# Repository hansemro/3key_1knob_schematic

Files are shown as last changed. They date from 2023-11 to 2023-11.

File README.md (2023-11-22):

3 Key + 1 Knob Minipad Schematic
================================

This repo contains an approximate KiCAD schematic and PCB layout for a 3 Key + 1 Knob minipad with
a CH552 USB MCU. Keys are each lit with an addressable NeoPixel (or similar) RGB LED.

## License

This work is licensed under a
[Creative Commons Attribution 4.0 International License][cc-by].

[][cc-by]

[cc-by]: http://creativecommons.org/licenses/by/4.0/
[cc-by-image]: https://i.creativecommons.org/l/by/4.0/88x31.png

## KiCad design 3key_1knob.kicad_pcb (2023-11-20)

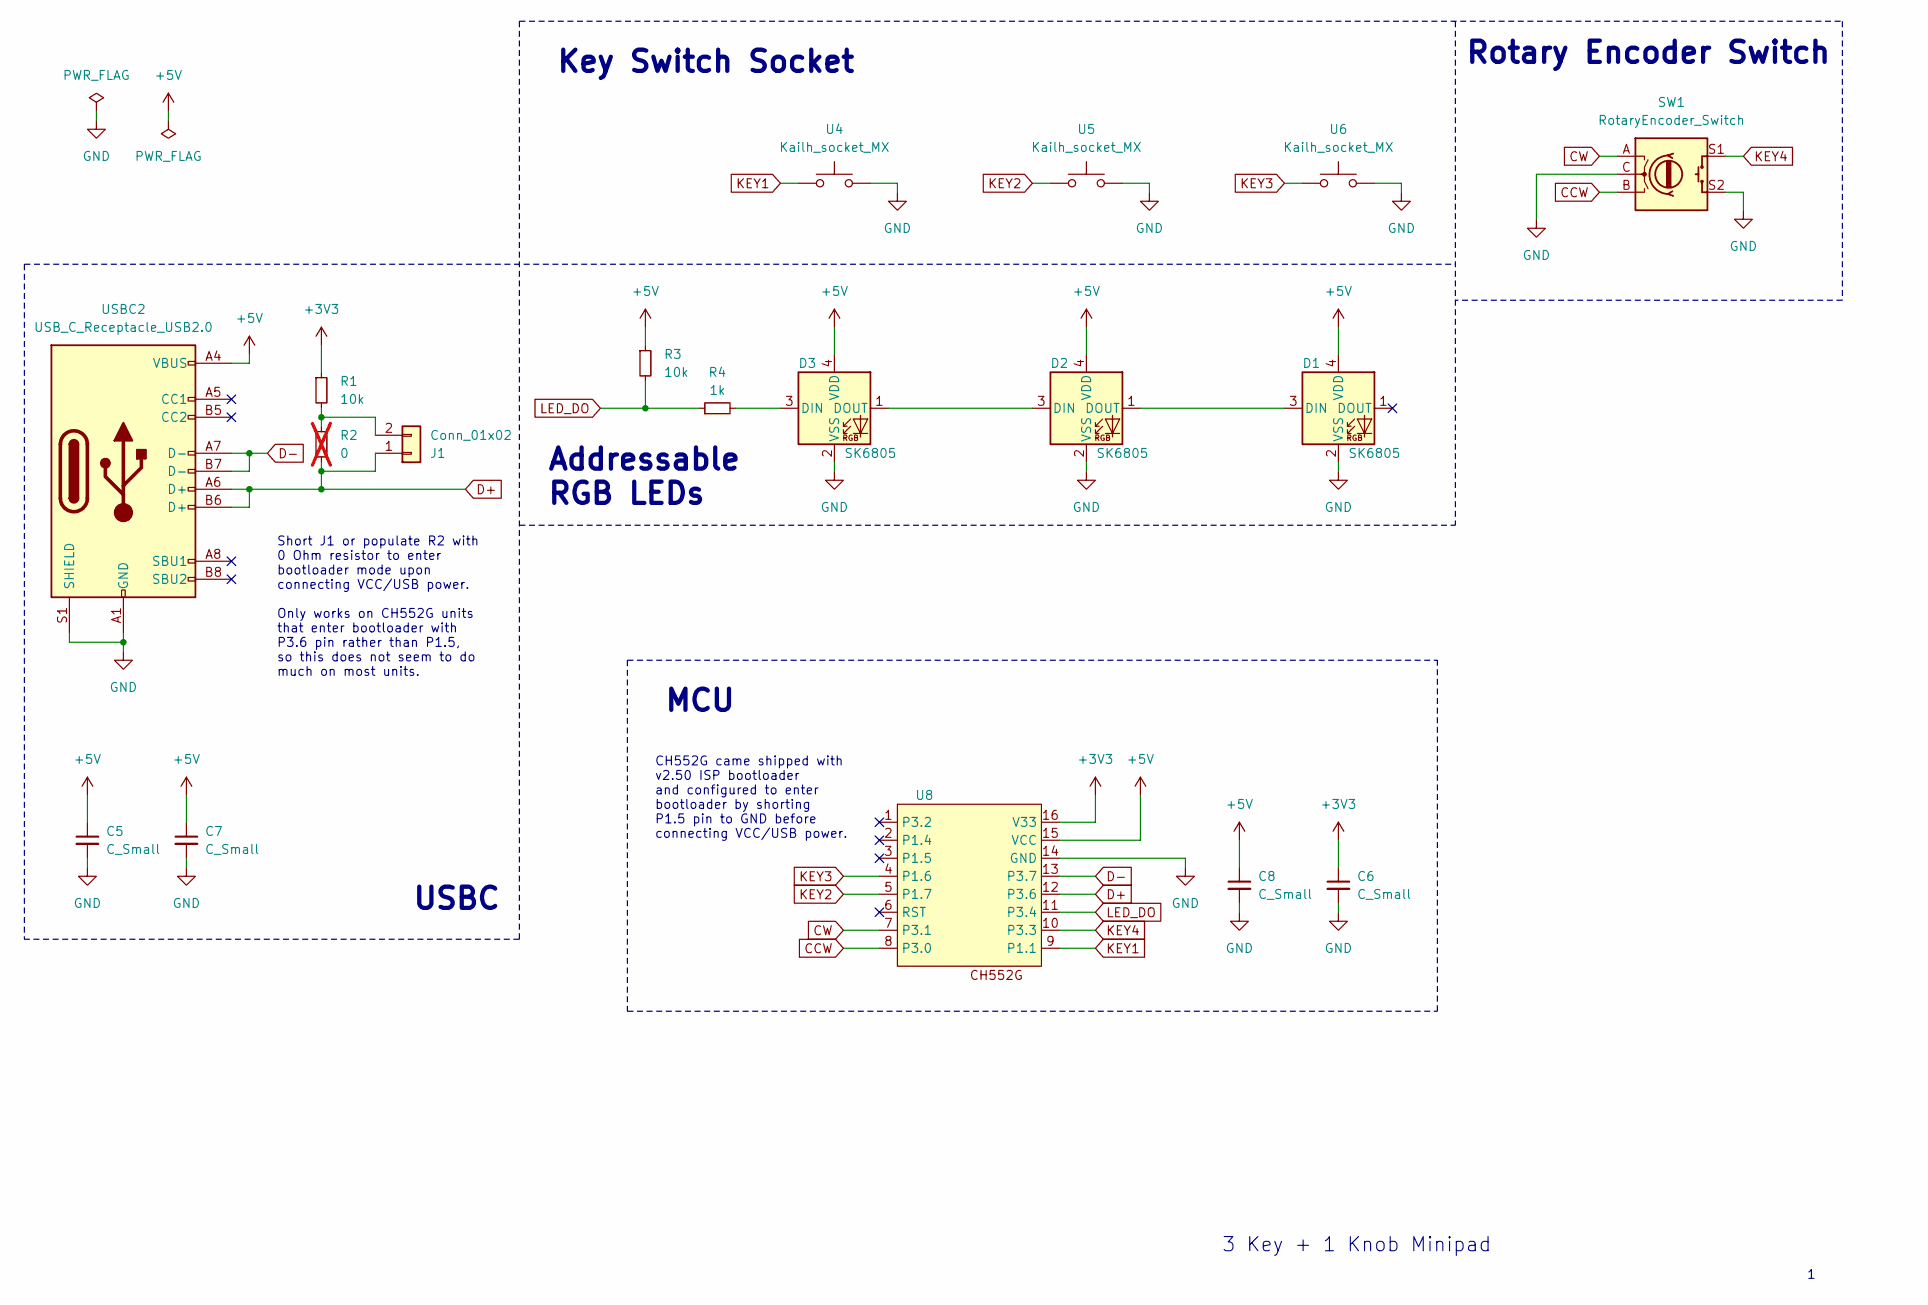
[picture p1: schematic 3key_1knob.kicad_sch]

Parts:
C5, C6, C7, C8: C_Small; C_0603_1608Metric
D1, D2, D3: SK6805; LED_SK6805_PLCC4_2.4x2.7mm_P1.3mm
J1: Conn_01x02; PinHeader_1x02_P1.27mm_Vertical
R1, R3: 10k; R_0603_1608Metric
R2: 0; R_0603_1608Metric; not fitted
R4: 1k; R_0603_1608Metric
SW1: RotaryEncoder_Switch; RotaryEncoder_Alps_EC12E-Switch_Vertical_H20mm
U4, U5, U6: Kailh_socket_MX
U8: SOP-16_3.9x9.9mm_P1.27mm
USBC2: USB_C_Receptacle_USB2.0; USB_C_Receptacle_GCT_USB4105-xx-A_16P_TopMnt_Horizontal

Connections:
+3V3: C6.1, R1.1, U8.16 (V33)
+5V: C5.1, C7.1, C8.1, D1.4 (VDD), D2.4 (VDD), D3.4 (VDD), R3.1, U8.15 (VCC), USBC2.A4 (VBUS), USBC2.A9 (VBUS), USBC2.B4 (VBUS), USBC2.B9 (VBUS)
CCW: SW1.B, U8.8 (P3.0)
CW: SW1.A, U8.7 (P3.1)
D+: J1.1, R2.2, U8.12 (P3.6), USBC2.A6 (D+), USBC2.B6 (D+)
D-: U8.13 (P3.7), USBC2.A7 (D-), USBC2.B7 (D-)
GND: C5.2, C6.2, C7.2, C8.2, D1.2 (VSS), D2.2 (VSS), D3.2 (VSS), SW1.C, SW1.S2, U4.2, U5.2, U6.2, U8.14 (GND), USBC2.A1 (GND), USBC2.A12 (GND), USBC2.B1 (GND), USBC2.B12 (GND), USBC2.S1 (SHIELD)
KEY1: U4.1, U8.9 (P1.1)
KEY2: U5.1, U8.5 (P1.7)
KEY3: U6.1, U8.4 (P1.6)
KEY4: SW1.S1, U8.10 (P3.3)
LED_DO: R3.2, R4.1, U8.11 (P3.4)
unnamed: D1.3 (DIN), D2.1 (DOUT)
unnamed: D2.3 (DIN), D3.1 (DOUT)
unnamed: D3.3 (DIN), R4.2
unnamed: J1.2, R1.2, R2.1

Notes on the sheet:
3 Key + 1 Knob Minipad
Short J1 or populate R2 with 0 Ohm resistor to enter bootloader mode upon connecting VCC/USB power. Only works on CH552G units that enter bootloader with P3.6 pin rather than P1.5, so this does not seem to do much on most units.
USBC
Key Switch Socket
MCU
Rotary Encoder Switch
CH552G came shipped with v2.50 ISP bootloader and configured to enter bootloader by shorting P1.5 pin to GND before connecting VCC/USB power.
Addressable RGB LEDs

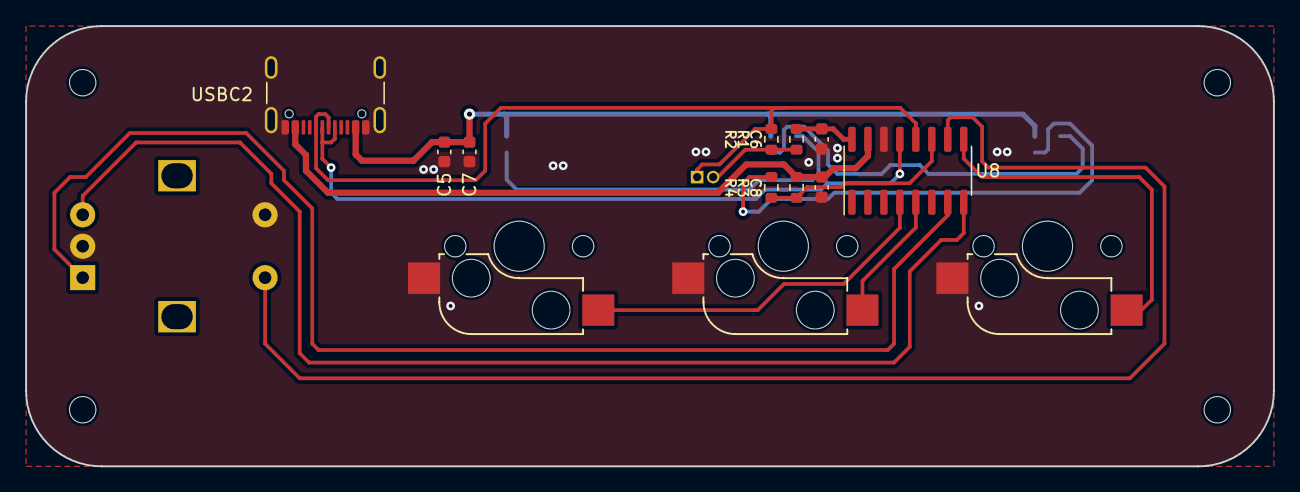
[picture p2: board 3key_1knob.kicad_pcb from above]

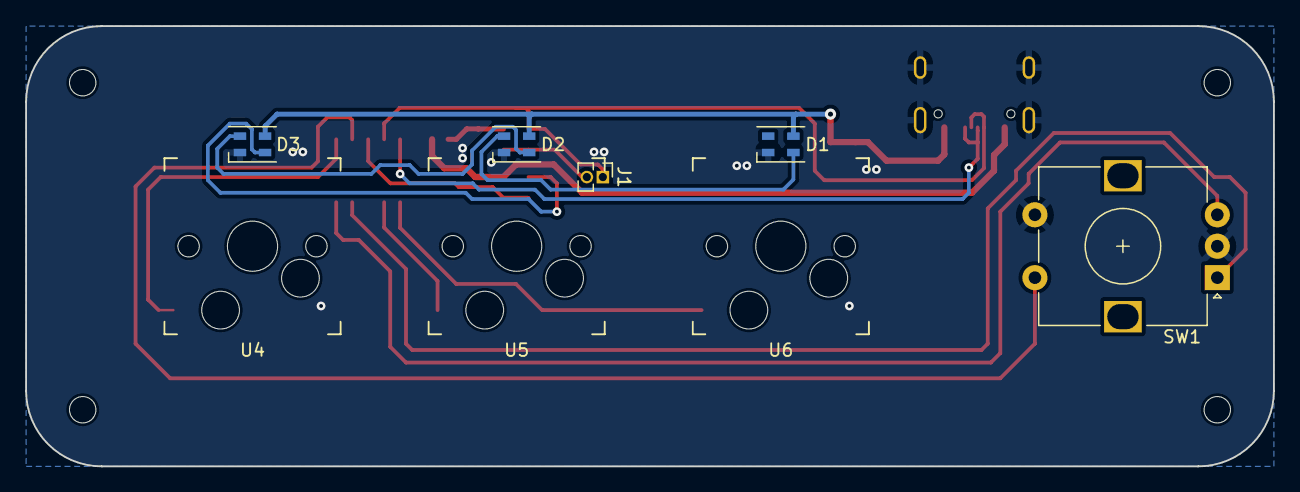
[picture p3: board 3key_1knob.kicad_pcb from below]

Board: 2 copper layers, 99.2 x 35.0 mm, 18 parts (8 on the bottom side), 16 nets.

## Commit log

2023-11-10 [WIP] Initial schematic and PCB drawings
    [3key_1knob.kicad_pcb, 3key_1knob.kicad_sch]
2023-11-11 Update PCB
    [3key_1knob.kicad_pcb]
2023-11-11 Unrouted PCB
    [3key_1knob.kicad_pcb]
2023-11-11 Remove drawings
    [3key_1knob.kicad_pcb]
2023-11-11 Use JLCPCB rules for 1-2 Layer PCB
2023-11-12 Route signals and power
    [3key_1knob.kicad_pcb]
2023-11-12 Finish ground fills; Add 2 pin header; Update 3D models
    This completes the PCB drawing based off the (questionable) original
    design. Due to odd signal routing, there are several ground fill islands
    that had to be addressed by placing microvias.
    Note that with JLCPCB DRC constraints, there will be some spacing
    violations due to the USBC footprint used. The USBC footprint has 2
    mounting holes which are too close to power pads.
    This also hides R2 resistor 3D model and displays 16-SOIC-3.9x9.9mm 3D
    model. For reference, R2 is unconnected, and 16-SOP-3.9x9.9mm lacks a 3D
    model so I used 16-SOIC variant instead.
    [3key_1knob.kicad_pcb, 3key_1knob.kicad_sch]
2023-11-12 Route LED_DO signal to MCU; Adjust trace thickness and ground fills
    This routes LED_DO which was previously unconnected to MCU, as well as
    increase trace thickness and use thermal relief pad connections on
    bottom ground fills.
    Thickness of power traces decreased to 0.5.
    Thickness of signal traces increased to 0.3.
    [3key_1knob.kicad_pcb]
2023-11-13 Minor PCB update
    [3key_1knob.kicad_pcb]
2023-11-20 Adjust LED positions and traces for better accuracy
    [3key_1knob.kicad_pcb]
2023-11-20 Connect USBC receptacle and Rotary Encoder shield to ground; Adjust traces
    [3key_1knob.kicad_pcb, 3key_1knob.kicad_sch]
2023-11-20 Update PCB measurement drawings
    [3key_1knob.kicad_pcb]
2023-11-20 Use solid ground fill for front layer (again)
    This reverts change that made front ground fill use thermal reliefs for
    pads due to introducing DRC violations around certain ground pads.
    Fixes: 05fae067c ("Connect USBC receptacle and Rotary Encoder shield to
    ground")
    [3key_1knob.kicad_pcb]
2023-11-20 Add mounting holes around corners
    [3key_1knob.kicad_pcb]
2023-11-20 Convert signal nets to global nets; Update sch description; Minor PCB trace update
    [3key_1knob.kicad_pcb, 3key_1knob.kicad_sch]
